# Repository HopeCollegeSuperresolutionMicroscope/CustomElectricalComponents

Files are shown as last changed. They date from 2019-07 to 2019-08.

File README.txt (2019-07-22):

#README

This Directory Serves To Store directions and specifications about electrical components of the microscope setup.

IMPORTANT Point about Schematics and EagleCAD:

	Schematics were created in EagleCAD free version.  These schematics make use of 3rd party libraries provided
        by sites like Element14 and handdrawn library parts based off of datasheets when not found.

	Opening a Schematic In EagleCAD:

		Since the free version of EagleCAD seems to limit all projects to the specific eagle/ folder designated
		 by the program on Install, it is recommended to move the schematic to this directory if intending to do 
		 work on the underlying schematic or pre-Gerber pcb board layout.

		In order to have access to the libraries, from the Eagle Control Panel: 
				Right click Libraries -> Library Manager
				Upper left Tab -> Available
				Browse -> Search for each library in EagleLibraries
				If the library is new it will be added in the Available dialog
				Click on the desired library and click Use button
				You should now see the library in the In Use Tab

Directory Layout:
	|
	|
	| ------- EagleLibraries/
	|		|	:Since Schematics were created in EagleCAD (freeware edition), additional libraries are housed here
	|		|
	|		|
	|		| ------- 3rdParty/ 
	|		|		: Part libraries that were imported from 3rd Party distributors.  See About.txt if wanting to look up revisions.
	|		|
	|		|
	|		| ------- HandCreated/
	|				: Parts that were created from Manufacturer DataSheets by individuals.  
	|				   Add the file name to Confirmed.txt when a pcb footprint has been used and verified.
	|
	|
	| ------- USB_TO_ILDA_Adapter/ 
	|		|	: Electronics for using ILDA device as a laser illumination source
	|		|
	|		|
	|		| ------- (Version) /
	|				|	:See About.txt for Version Different highlights
	|				|
	|				|
	|				| ------- Schematics/
	|				|		: Electrical Connection Schematics
	|				|
	|				|
	|				| ------- Gerber/
	|				|		: Gerber Files for PCBs that have been proven 
	|				|
	|				|
	|				| ------ DataSheets/
	|						: DataSheets Related to important components (ICs at the very least)
	|				
	|
	| ------ USB_TO_RS485_Connection/
	|		|	:Electronic connector and connections for RS-485 Comm with OrientalMotors CRPK
	|		|
	|		|
	|		| ------ Schematics/
	|		|		: Electrical Connections (Since this is a non-standard connection)
	|		|
	|		|
	|		| ------ DataSheets/
	|		|		: DataSheets related to important Components (motor controller and USB adapter)
	|		|
	|		|
	|		| ------ Figures/
	|				: Explanations for adapting the non-standard connection
	|		
	|
	| ------ Power_Supply/
			|	:Electrical connections for using Wall Power to provide stable voltage to OrientalMotors CRPK
			|
			|
			| ------ Schematics/
			|		: Electrical Connections (For pins to terminals etc.)
			|
			|
			| ------ DataSheets/ 
			|		: DataSheets related to important components
			|
			|
			| ------ Figures/
					:Explanation for making connections if there is a difficulty

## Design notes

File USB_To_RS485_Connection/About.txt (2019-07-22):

#About

For the chosen stepper motor from Oriental Motor LLC, a driver is required that must be communicated
with via RS485 protocol.  In order to interface such communication with micro-manager on a PC,
a USB To RS485 adapter must be purchased.

The documentation pertaining to this particular adapter is in regards to the recommended adapter
by Oriental Motor.  Please note, Oriental Motor requires a custom wiring of Ethernet wires into
the adapter.  DO NOT order adapters that are simply listed as USB to RS-485, as Oriental Motor
uses a non-standard wire configuration into their units.  

The appropriate instructions for assembling an RS-485 Adapter with an ethernet cable can be found
in the Schematics Folder.

    Necessary tools: 

		Miniature flat-head screw driver
		Wire Stripper
		Fine Wire Stripper (for stripping the ethernet wires)

See the Documentation and datasheets.

In regards to the driver written for the Autofocus motor at the other end, it must be noted
that the driver IS NOT adapter agnostic.  It makes use of the FTDI USB chip and drivers.  If may
be possible to use another adapter, but one must make certain that it is an FTDI based adapter.

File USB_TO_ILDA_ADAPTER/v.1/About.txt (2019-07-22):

#Version 1
#About.txt

This is the follow-up theoretical designed controller for compliance with the ILDA IO standard.  This
standard requires differential signals at the inputs and it's lack of firm discussion on pin sinking
require a more robust account for potential "operational signal" current draw.

Additionally, DAC power is supplied via wall power with regulators, in order to reduce fluctuations
in voltage that can occur by overloading the load on a set of USB buses for a computer. 

Schematic:

    The schematic is done in theory, but may need revisions upon breadboarding or pcb testing in an 
actual setup.

PCB:

   The PCB has not yet been arranged nor has a breadboard been proven yet.  A finalized Gerber file
should be introduced after a successful iteration and testing.

Software

    C++ code was written as a .dll on Micro-manager for the alpha version explicitly. The Version 1
attempts to implement the same USB bridge triggers so that there is no need to change the .dll for
the sake of changing hardware.

Further expansions to the other optional ILDA pins may be achieved in a future iteration with adjustments 
to the .dll.

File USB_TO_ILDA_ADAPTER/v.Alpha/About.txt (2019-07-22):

#Version Alpha
#About.txt

The first prototype that was used to maintain a stable control over the PRO-1600RGB laser from 
Laserworld.  This prototype is what was used to do primary testing and proof of this system as
integrated into uManager microscopy setup software.  It, however, implements an erroneous reading
of the ILDA standard and as such is not guaranteed to work with all ILDA IO pins.

As such, this alpha version stands as proof of control of the PRO-1600RGB and may be tested against 
other ILDA laser boxes if so desired to ensure performance. 

Schematic:

    The schematic makes use of a Deprected switch (see schematic itself for details).  This switch
will become a production chokepoint.  Efforts to formalize and proof v1.0 move toward this.

PCB:

   The alpha prototype exists in a breadboarded state in the setup this lab tested against.  As such,
there are no Gerber files at this moment.  It is seen as a better use of time to work on proving
the v1.0 PCB instead.  The following version however will require a reworking of uManager Device 
Library code to accomodate an increase in IO if that is desired.

Software

    C++ code was written as a .dll on Micro-manager for the alpha version explicitly.  In order to 
test the setup this lab used.

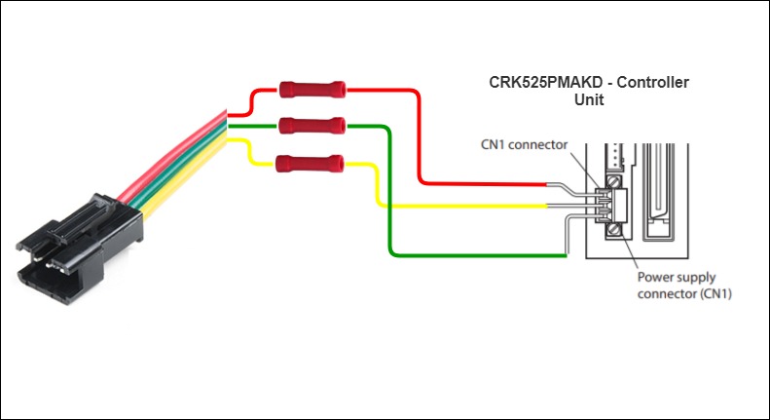
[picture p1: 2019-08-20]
Autofocus_Motor_Power_Supply/Schematics/PowerSupplyCableConnection.jpg

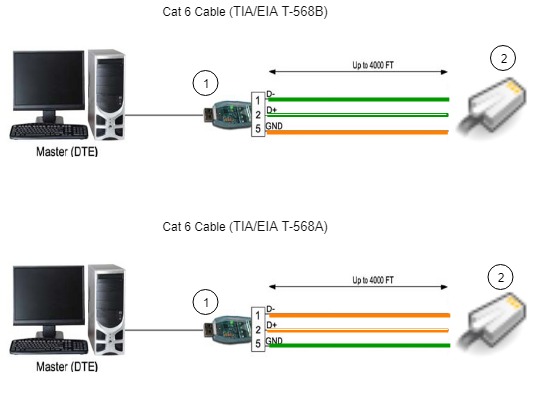
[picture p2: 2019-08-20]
Autofocus_Motor_Power_Supply/Schematics/ConnectingServoToComputer.jpg

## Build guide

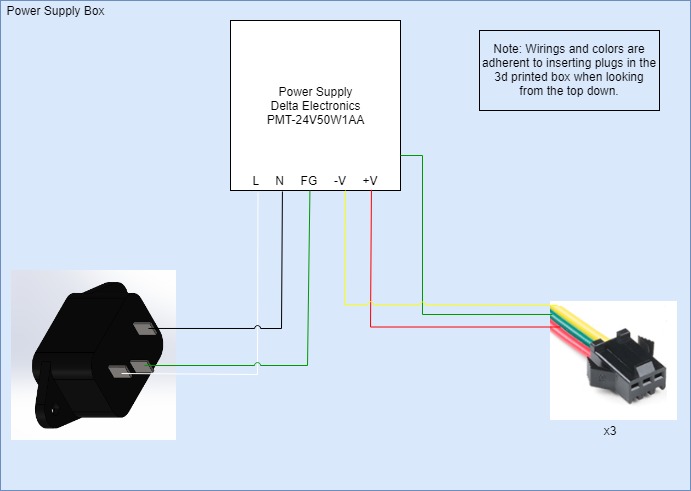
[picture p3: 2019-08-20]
Autofocus_Motor_Power_Supply/Schematics/PowerSupplyInternalWiring.jpg

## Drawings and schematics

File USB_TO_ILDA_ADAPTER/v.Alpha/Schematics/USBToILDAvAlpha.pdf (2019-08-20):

# GND ⁺⁵V

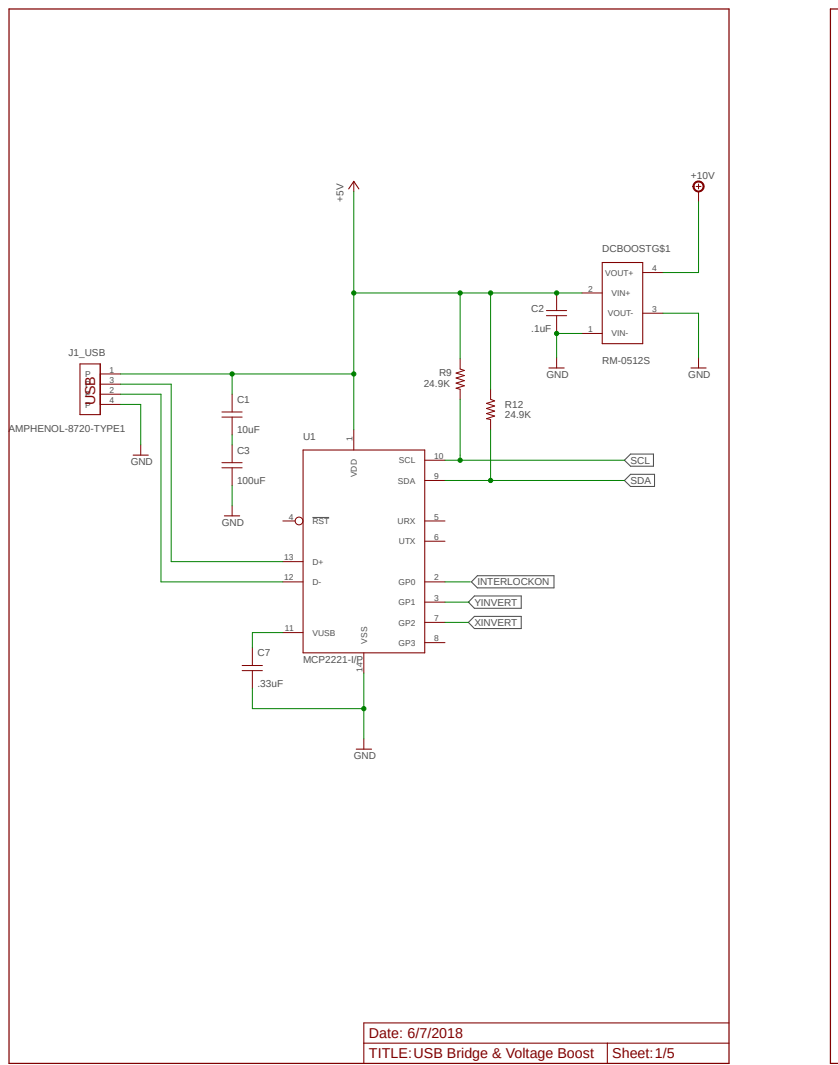
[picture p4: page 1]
MCP2221-I/P; AMPHENOL-8720-TYPE1; GND; VDD; J1_USB; DCBOOSTG$1 VIN- 1; VIN+ 2; VOUT-; 3 VOUT+; SCL; YINVERT; XINVERT; INTERLOCKON; SDA; USB Bridge & Voltage Boost; 1/5 USB; Date:; TITLE:; Sheet:

1 VSS 14 D+ 13 D- 12 SCL 10 SDA 9 URX 5 UTX 6 GP0 2 GP1 3 GP2 7 GP3 8 RST 4 VUSB 11

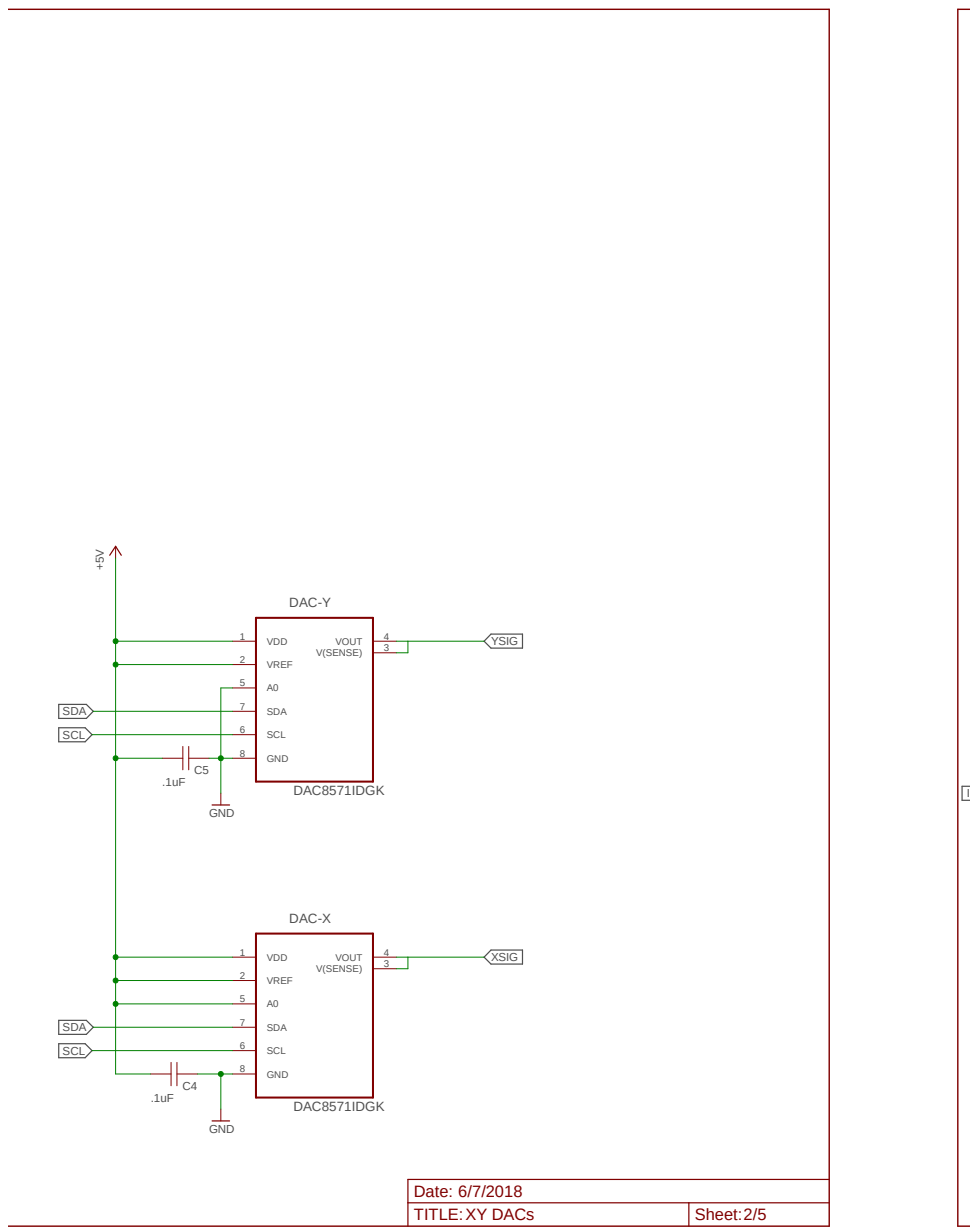
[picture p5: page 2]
DAC8571IDGK; GND; GND ⁺⁵V; VDD 1; VREF 2; SDA 7; SCL 6; GND 8; VOUT; 4 V(SENSE); 3 DAC-Y; 3 DAC-X; YSIG; XSIG; SCL; INTERLOCKON; SDA; XY DACs

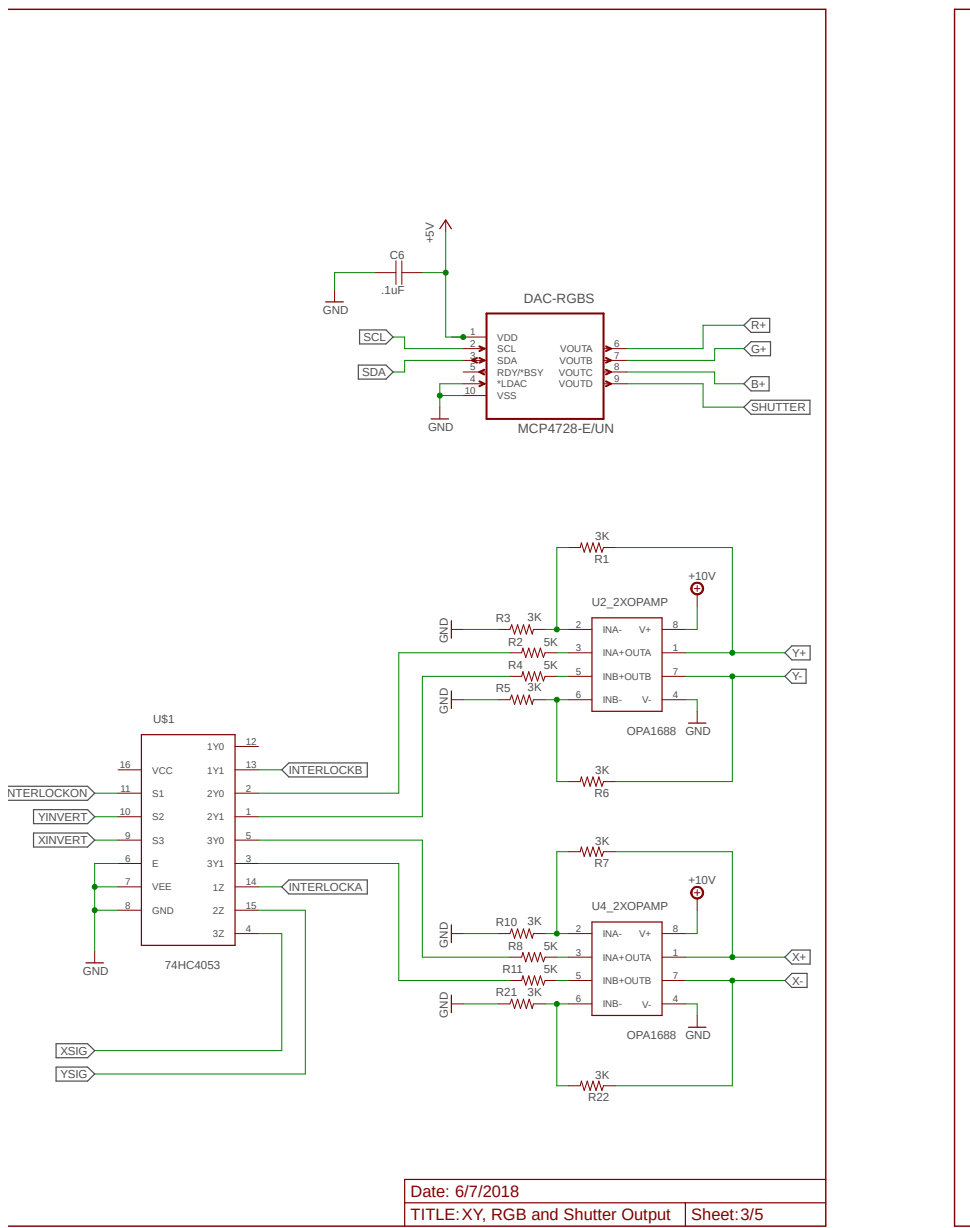
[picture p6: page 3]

GND GND

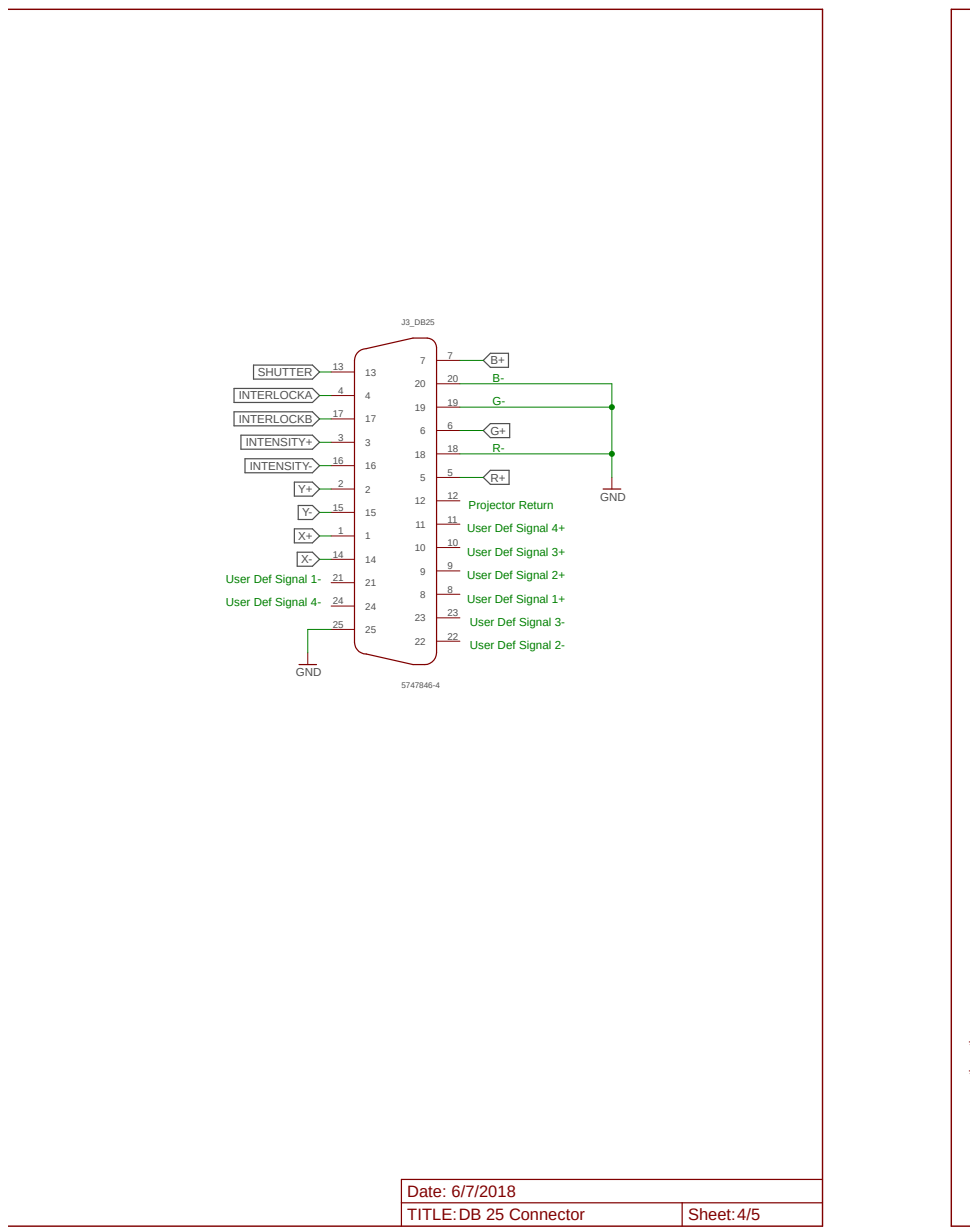
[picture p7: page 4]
5747846-4 GND; GND; SHUTTER; INTENSITY+; INTENSITY-; INTERLOCKB; INTERLOCKA; DB 25 Connector; User Def Signal 3+; User Def Signal 4+; Projector Return

User Def Signal 2+
User Def Signal 1+
User Def Signal 3-
User Def Signal 2-

User Def Signal 1-
User Def Signal 4-

* List is non-exhaustive and seeks to use proven ICs from the Alpha version
** See ILDA standards to confirm. These are the most glaring issues.

## RGB & Shutter Voltage

5/5

# Alpha Version Notes:

# Setup is proven against PRO-1600RGB from Laserworld, but DOES NOT adhere

to ILDA specifcation.

# Changes Needed For ILDA Conformance**

# +/- Signals need to be differential not ground referenced

# Separate Power supply to account for lax current spec (USB cannot meet the maximum circumstance)

# Improvements From Alpha:*

# ILDA Standard Conformance

# 74HC4503 is deprecated and must be replaced

# PCB must be finalized and tested for conformance (Alpha was in a breadboard)

# Move to External Power and regulation (USB fluctuates due to loads)

## * List is non-exhaustive and seeks to use proven ICs from the Alpha version

** See ILDA standards to confirm. These are the most glaring issues.
Other non-important conformance may be additional IO connections on the DB-25 Connector, etc.

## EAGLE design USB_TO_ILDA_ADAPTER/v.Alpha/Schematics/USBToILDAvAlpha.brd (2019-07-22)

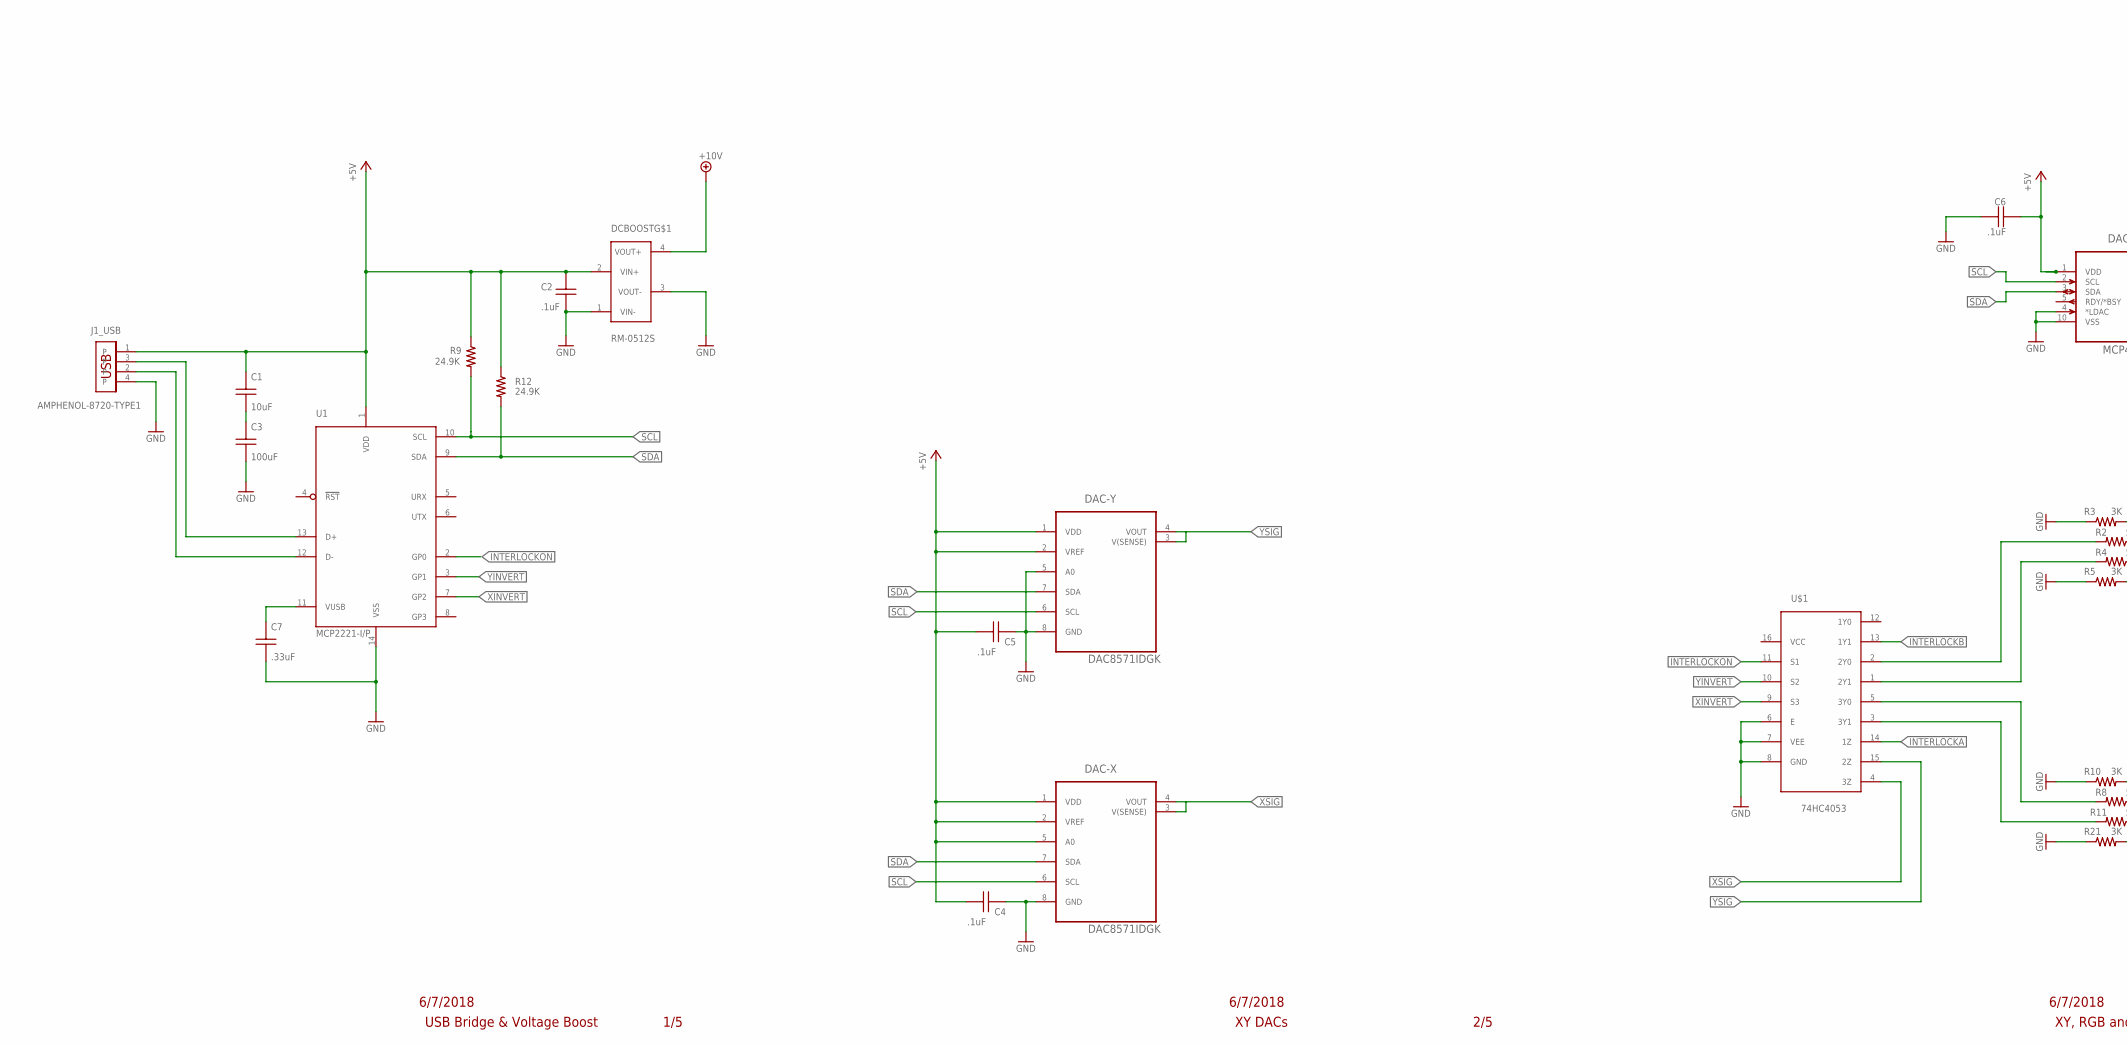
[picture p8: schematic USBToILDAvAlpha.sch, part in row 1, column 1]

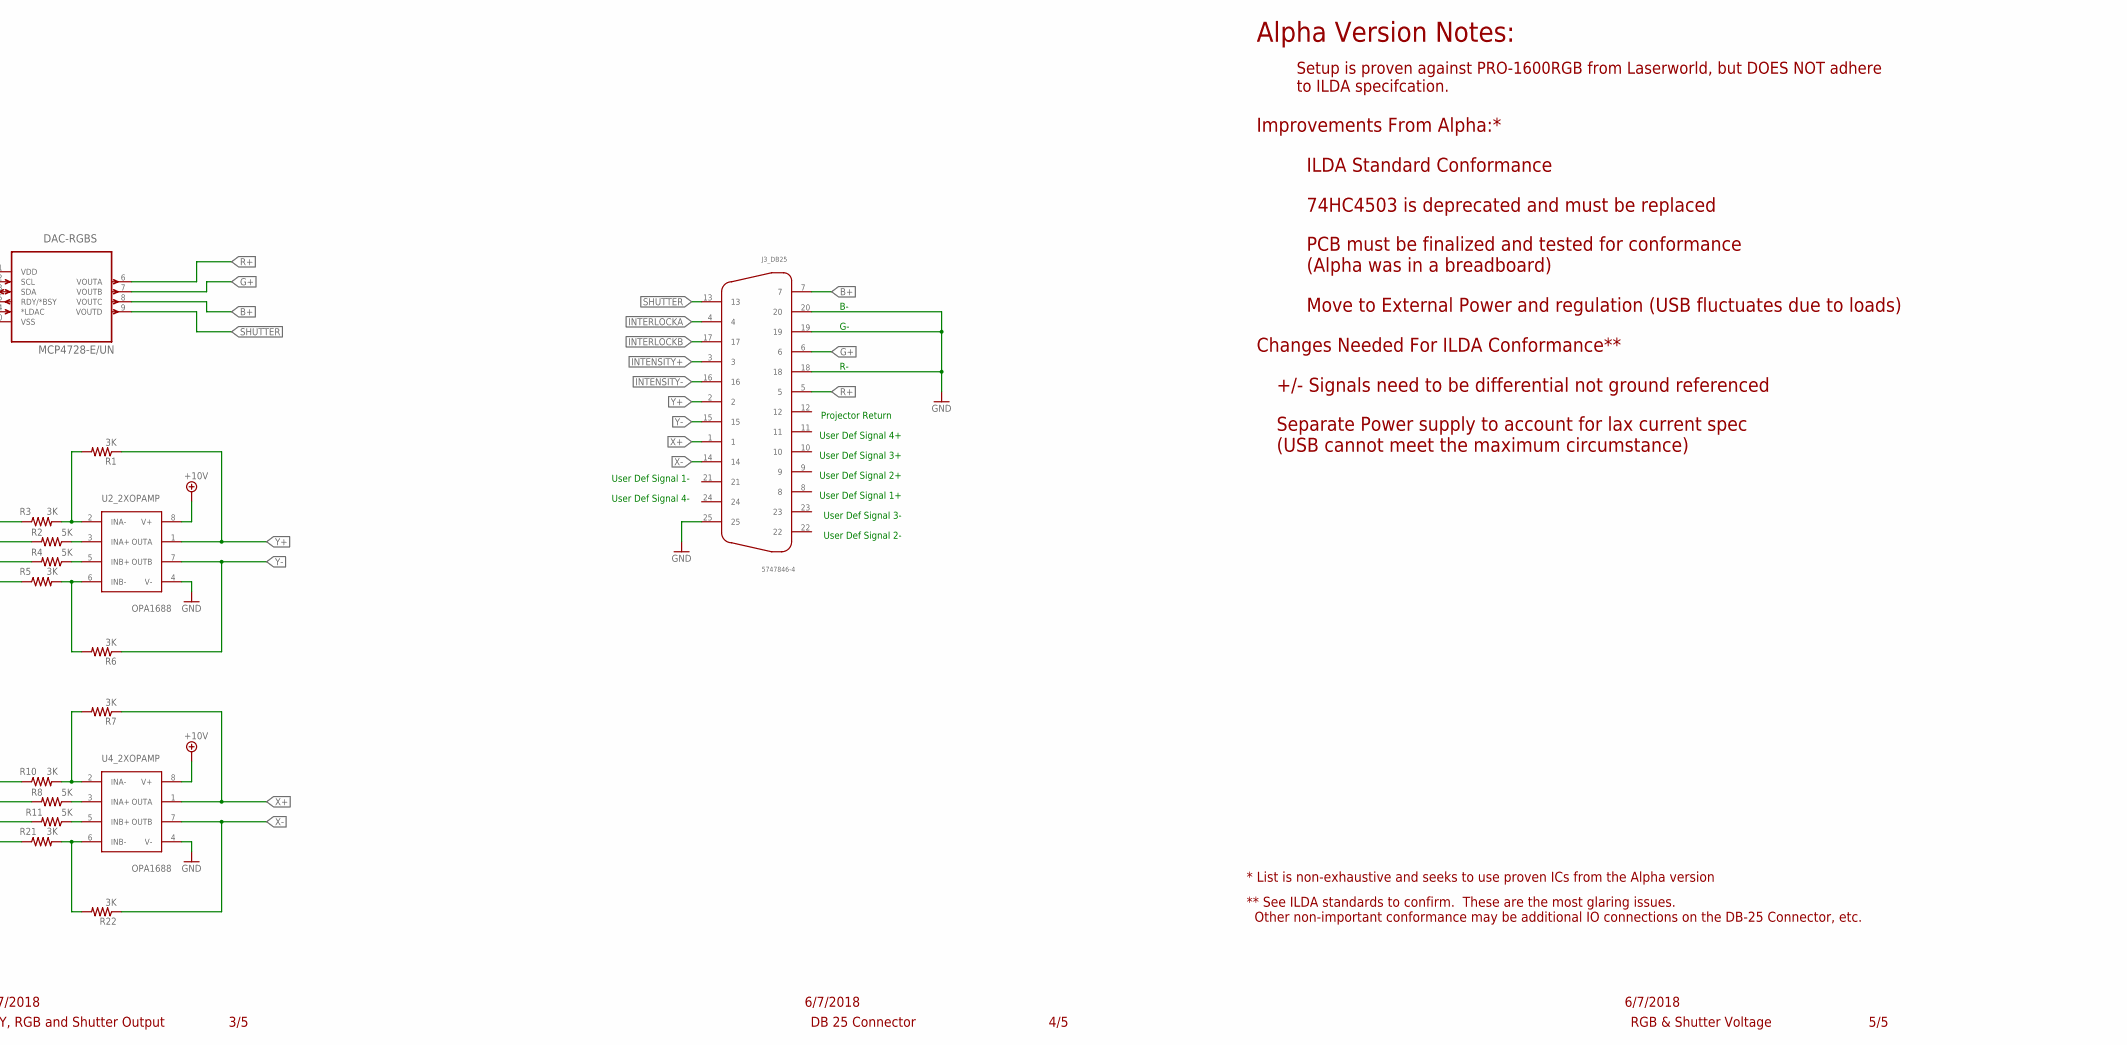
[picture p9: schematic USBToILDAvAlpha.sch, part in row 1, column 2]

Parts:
C1: 10uF; WM1
C2, C4, C5, C6: .1uF; WM1
C3: 100uF; WM1
C7: .33uF; WM1
DAC-RGBS: MCP4728-E/UN; SOP50P490X110-10N
DAC-X: DAC8571IDGK; SOP65P490X110-8N
DAC-Y: DAC8571IDGK; SOP65P490X110-8N
DCBOOST: RM-0512S; SIP-4
J1_: AMPHENOL-8720-TYPE1; 87520
J3_: 5747846-4
R1, R3, R5, R6, R7, R10, R21, R22: 3K; R01005
R2, R4, R8, R11: 5K; R01005
R9, R12: 24.9K; R01005
U1: MCP2221-I/P; DIL14
U2, U4: OPA1688; SOIC-8
U$1: 74HC4053; SO16

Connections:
+5V: C1.P$1 (A), C2.P$1 (A), C4.P$1 (A), C5.P$1 (A), C6.P$2 (B), DAC-RGBS.1 (VDD), DAC-X.1 (VDD), DAC-X.2 (VREF), DAC-X.5 (A0), DAC-Y.1 (VDD), DAC-Y.2 (VREF), DCBOOST.2 (VIN+), J1_.1, R9.1, R12.1, U1.1 (VDD)
+9V: DCBOOST.4 (VOUT+)
+10V: U2.8 (V+), U4.8 (V+)
B+: DAC-RGBS.8 (VOUTC), J3_.7
G+: DAC-RGBS.7 (VOUTB), J3_.6
GND: C2.P$2 (B), C3.P$2 (B), C4.P$2 (B), C5.P$2 (B), C6.P$1 (A), C7.P$2 (B), DAC-RGBS.4 (*LDAC), DAC-RGBS.10 (VSS), DAC-X.8 (GND), DAC-Y.5 (A0), DAC-Y.8 (GND), DCBOOST.1 (VIN-), DCBOOST.3 (VOUT-), J1_.4, J3_.18, J3_.19, J3_.20, J3_.25, R3.1, R5.1, R10.1, R21.1, U1.14 (VSS), U2.4 (V-), U4.4 (V-), U$1.6 (E), U$1.7 (VEE), U$1.8 (GND)
INTENSITY+: J3_.3
INTENSITY-: J3_.16
INTERLOCKA: J3_.4, U$1.14 (1Z)
INTERLOCKB: J3_.17, U$1.13 (1Y1)
INTERLOCKON: U1.2 (GP0), U$1.11 (S1)
unnamed: C1.P$2 (B), C3.P$1 (A)
unnamed: J1_.2, U1.12 (D-)
unnamed: J1_.3, U1.13 (D+)
unnamed: R1.2, R3.2, U2.2 (INA-)
unnamed: R2.1, U2.3 (INA+)
unnamed: R2.2, U$1.2 (2Y0)
unnamed: R7.2, R10.2, U4.2 (INA-)
unnamed: R8.1, U4.3 (INA+)
unnamed: R8.2, U$1.5 (3Y0)
unnamed: R4.2, U$1.1 (2Y1)
unnamed: R4.1, U2.5 (INB+)
unnamed: R11.2, U$1.3 (3Y1)
unnamed: R5.2, R6.2, U2.6 (INB-)
unnamed: C7.P$1 (A), U1.11 (VUSB)
unnamed: R11.1, U4.5 (INB+)
unnamed: R21.2, R22.2, U4.6 (INB-)
R+: DAC-RGBS.6 (VOUTA), J3_.5
SCL: DAC-RGBS.2 (SCL), DAC-X.6 (SCL), DAC-Y.6 (SCL), R9.2, U1.10 (SCL)
SDA: DAC-RGBS.3 (SDA), DAC-X.7 (SDA), DAC-Y.7 (SDA), R12.2, U1.9 (SDA)
SHUTTER: J3_.13
X+: J3_.1, R7.1, U4.1 (OUTA)
X-: J3_.14, R22.1, U4.7 (OUTB)
XINVERT: U1.7 (GP2), U$1.9 (S3)
XSIG: DAC-X.3 (V(SENSE)), DAC-X.4 (VOUT), U$1.4 (3Z)
Y+: J3_.2, R1.1, U2.1 (OUTA)
Y-: J3_.15, R6.1, U2.7 (OUTB)
YINVERT: U1.3 (GP1), U$1.10 (S2)
YSIG: DAC-Y.3 (V(SENSE)), DAC-Y.4 (VOUT), U$1.15 (2Z)

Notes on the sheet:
User Def Signal 1+
User Def Signal 2+
User Def Signal 3+
User Def Signal 4+
Projector Return
User Def Signal 1-
User Def Signal 2-
User Def Signal 3-
User Def Signal 4-
6/7/2018
RGB & Shutter Voltage
4/5
DB 25 Connector
5/5
USB Bridge & Voltage Boost
1/5
XY, RGB and Shutter Output
3/5
XY DACs
2/5
Alpha Version Notes:
Setup is proven against PRO-1600RGB from Laserworld, but DOES NOT adhere to ILDA specifcation.
Changes Needed For ILDA Conformance**
+/- Signals need to be differential not ground referenced
Separate Power supply to account for lax current spec (USB cannot meet the maximum circumstance)
Improvements From Alpha:*
ILDA Standard Conformance
74HC4503 is deprecated and must be replaced
PCB must be finalized and tested for conformance (Alpha was in a breadboard)
Move to External Power and regulation (USB fluctuates due to loads)
* List is non-exhaustive and seeks to use proven ICs from the Alpha version
** See ILDA standards to confirm. These are the most glaring issues. Other non-important conformance may be additional IO connections on the DB-25 Connector, etc.

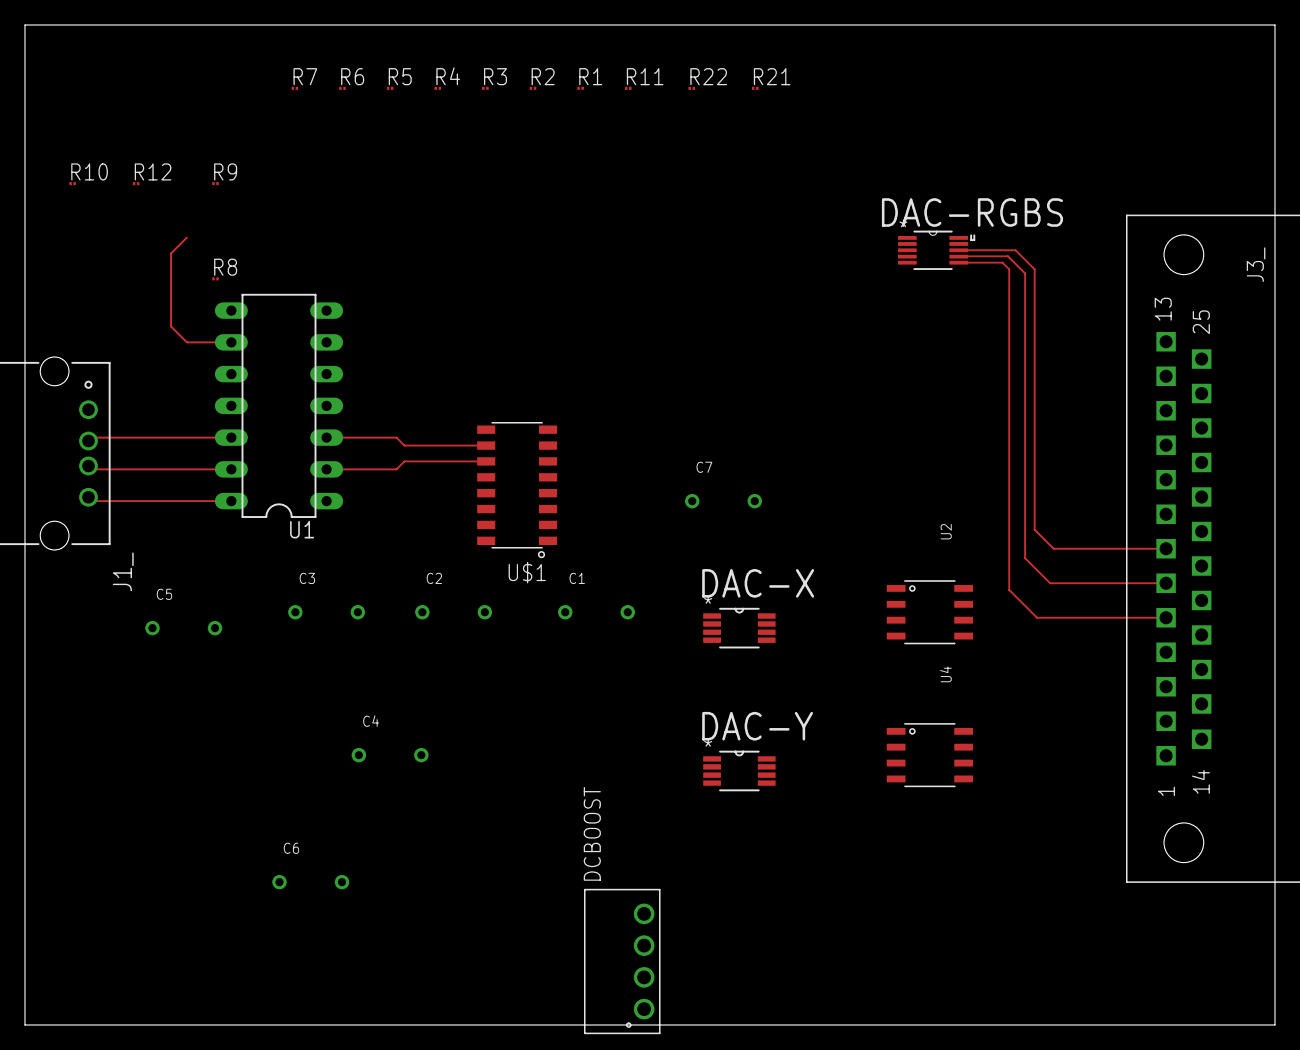
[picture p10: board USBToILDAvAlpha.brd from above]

Board: 2 copper layers, 100.0 x 80.0 mm, 31 parts (0 on the bottom side), 35 nets.

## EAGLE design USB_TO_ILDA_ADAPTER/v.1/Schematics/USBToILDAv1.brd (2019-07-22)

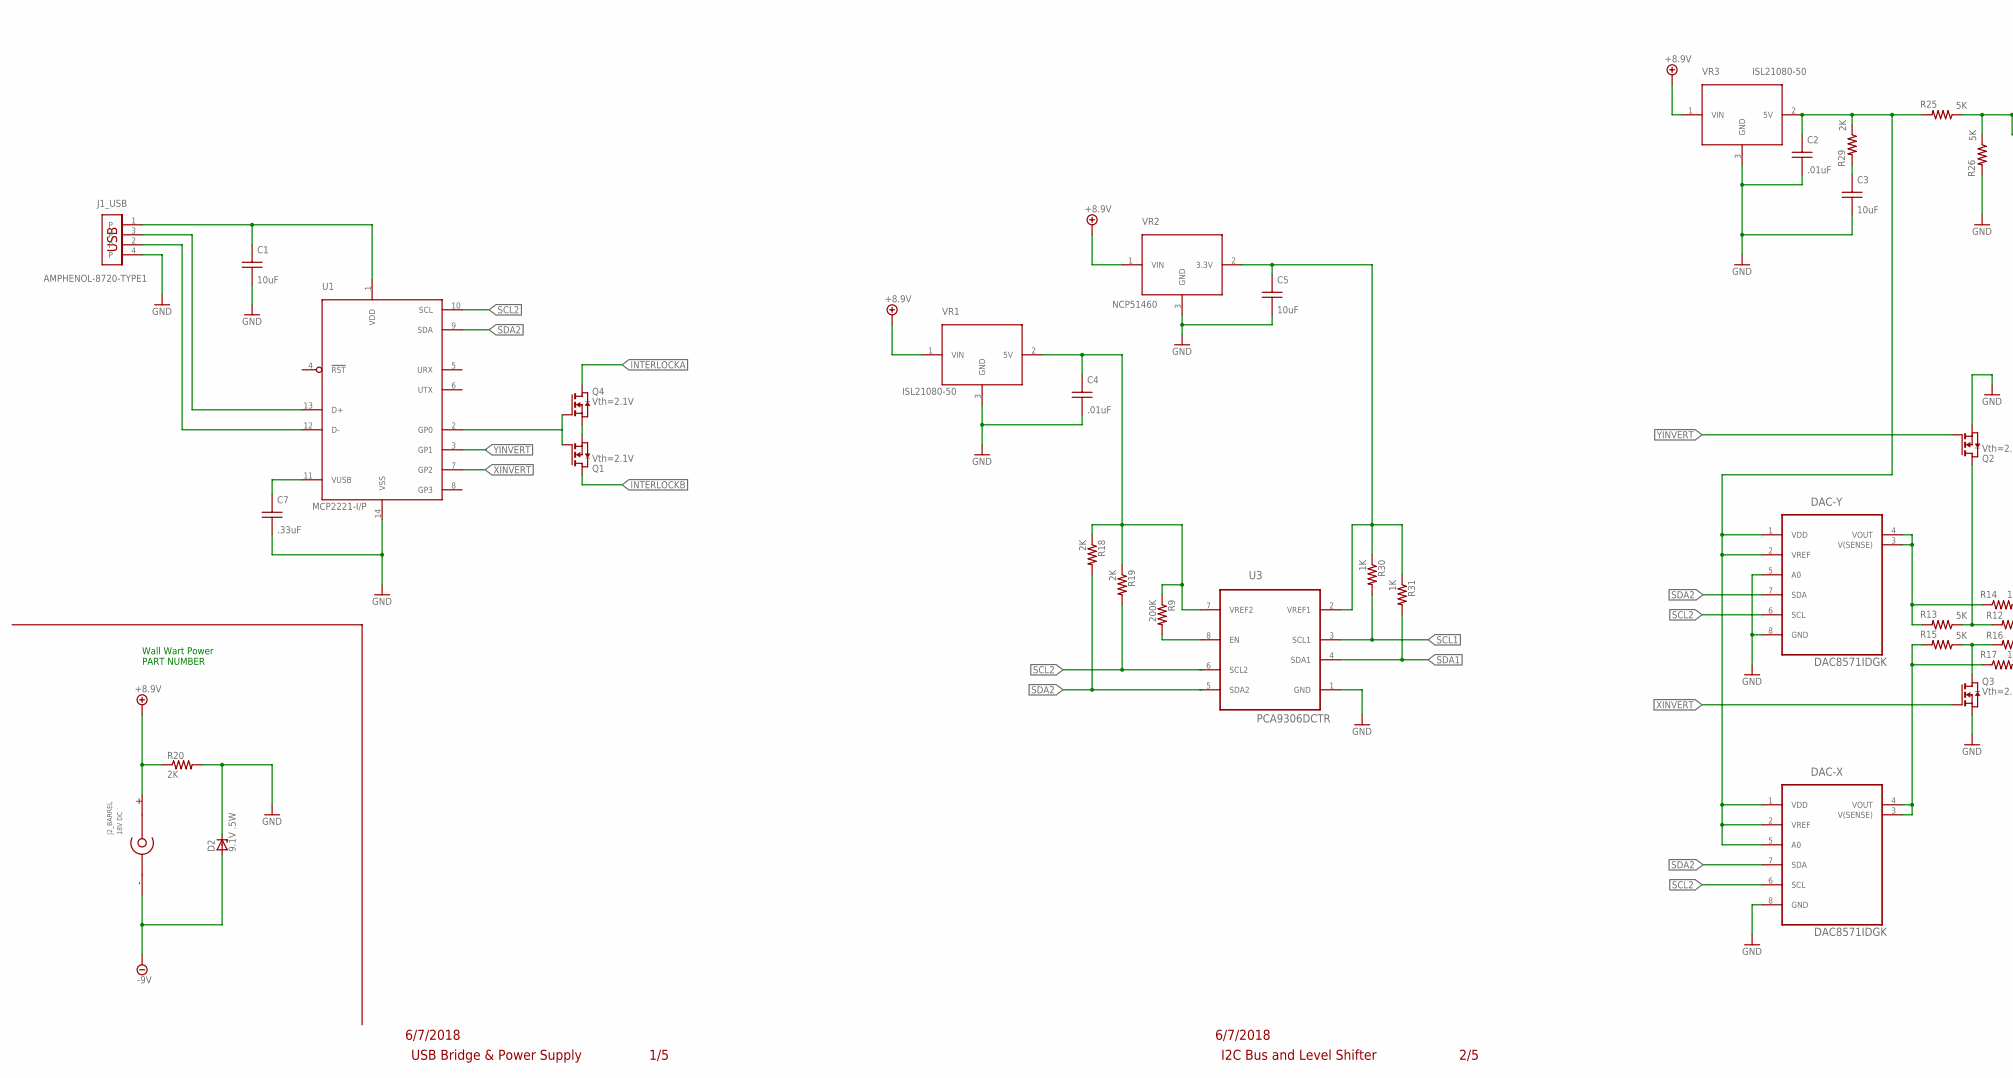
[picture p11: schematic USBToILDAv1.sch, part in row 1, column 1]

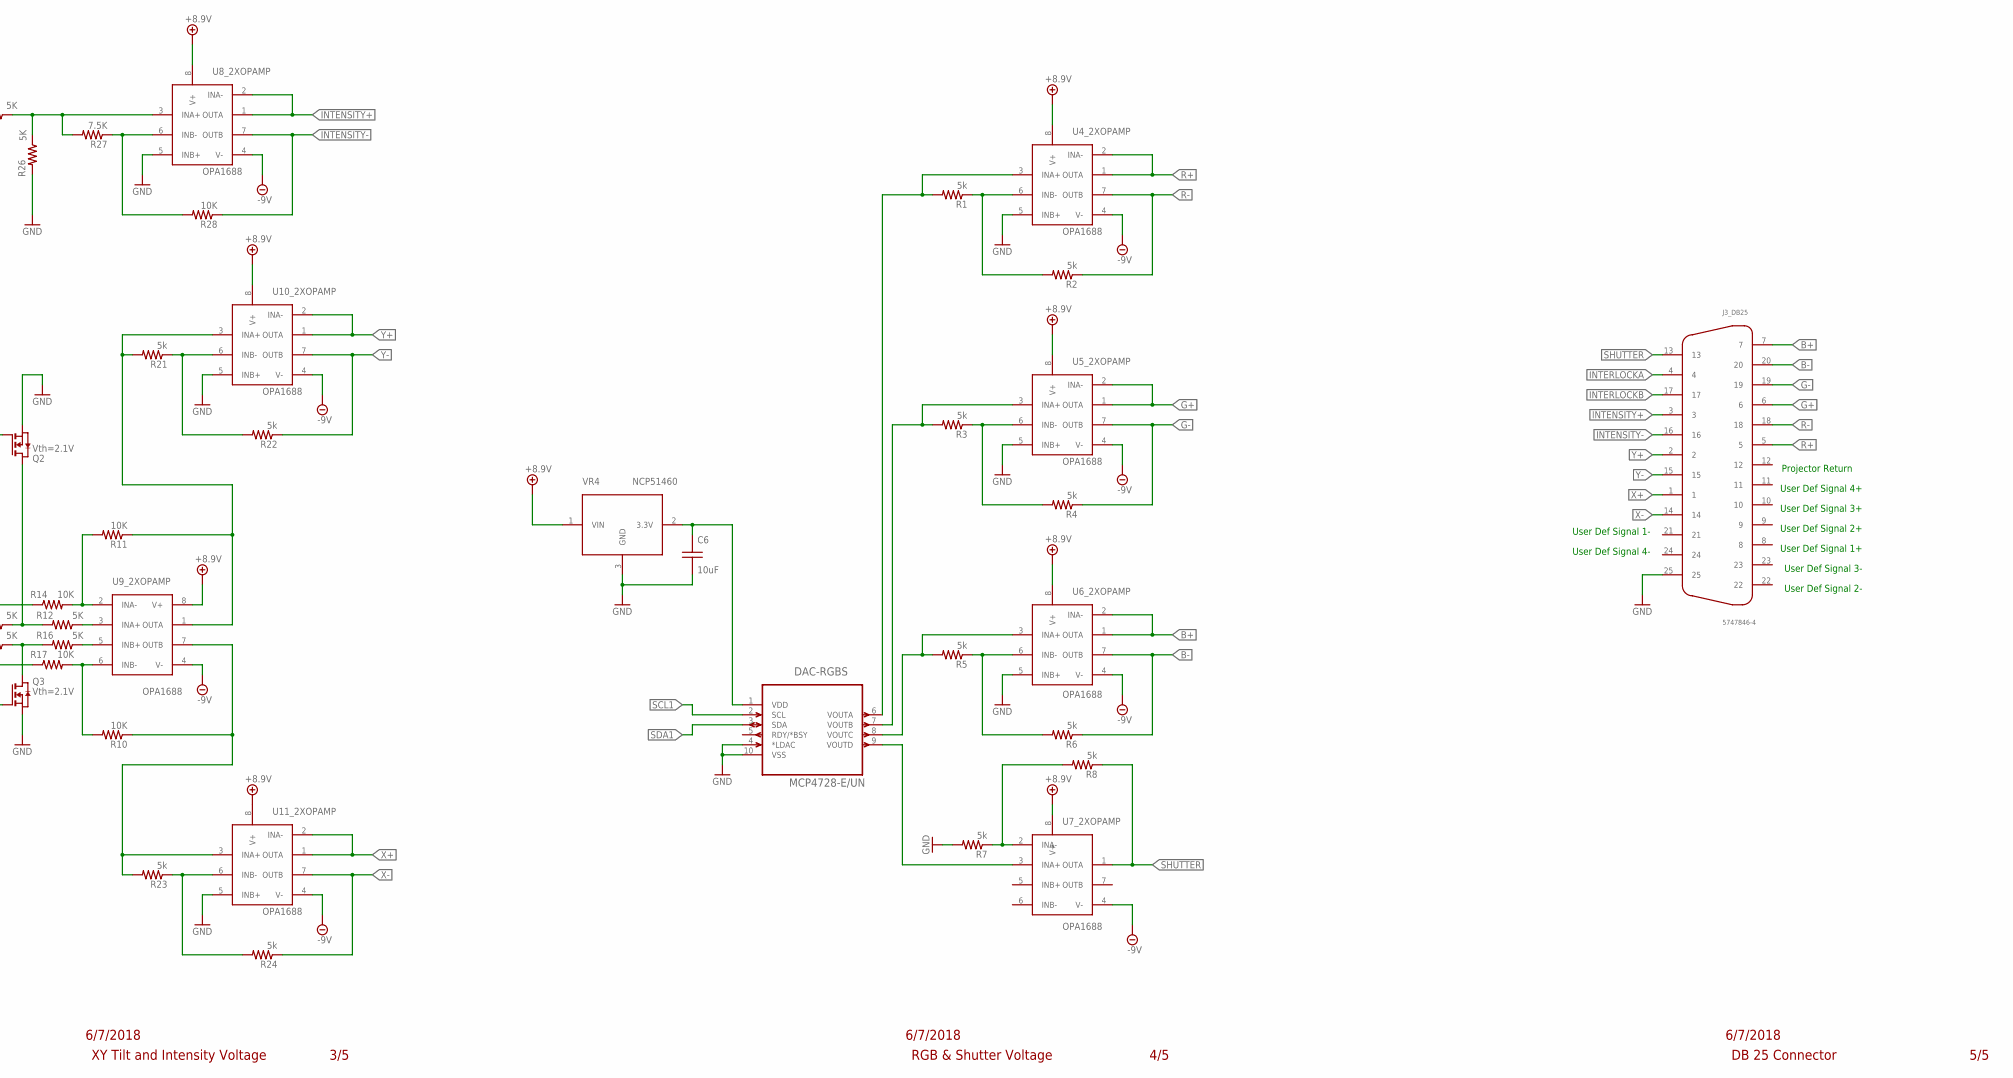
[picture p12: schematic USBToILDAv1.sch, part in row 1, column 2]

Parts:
C1, C3, C5, C6: 10uF; WM1
C2, C4: .01uF; WM1
C7: .33uF; WM1
D2: 9.1V .5W; DO35Z10
DAC-RGBS: MCP4728-E/UN; SOP50P490X110-10N
DAC-X: DAC8571IDGK; SOP65P490X110-8N
DAC-Y: DAC8571IDGK; SOP65P490X110-8N
J1_: AMPHENOL-8720-TYPE1; 87520
J2_BARREL: 18V DC; PJ-036AH-SMT-TR
J3_: 5747846-4
Q1, Q2, Q3, Q4: Vth=2.1V; SOT-26
R1, R2, R3, R4, R5, R6, R7, R8, R21, R22, R23, R24: 5k; R01005
R9: 200K; R01005
R10, R11, R14, R17, R28: 10K; R01005
R12, R13, R15, R16, R25, R26: 5K; R01005
R18, R19, R20, R29: 2K; R01005
R27: 7.5K; R01005
R30, R31: 1K; R01005
U1: MCP2221-I/P; DIL14
U3: PCA9306DCTR; SOP65P400X130-8N
U4, U5, U6, U7, U8, U9, U10, U11: OPA1688; SOIC-8
VR1, VR3: ISL21080-50; SOT23-CASE308
VR2, VR4: NCP51460; SOT-23-CASE318

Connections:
+8.9V: J2_BARREL.1 (+), R20.1, U4.8 (V+), U5.8 (V+), U6.8 (V+), U7.8 (V+), U8.8 (V+), U9.8 (V+), U10.8 (V+), U11.8 (V+), VR1.1 (VIN), VR2.1 (VIN), VR3.1 (VIN), VR4.1 (VIN)
-9V: D2.A, J2_BARREL.2 (-), J2_BARREL.3 (-), U4.4 (V-), U5.4 (V-), U6.4 (V-), U7.4 (V-), U8.4 (V-), U9.4 (V-), U10.4 (V-), U11.4 (V-)
B+: J3_.7, U6.1 (OUTA), U6.2 (INA-)
B-: J3_.20, R6.1, U6.7 (OUTB)
G+: J3_.6, U5.1 (OUTA), U5.2 (INA-)
G-: J3_.19, R4.1, U5.7 (OUTB)
GND: C2.P$2 (B), C3.P$2 (B), C4.P$2 (B), C5.P$2 (B), C6.P$2 (B), C7.P$2 (B), D2.C, DAC-RGBS.4 (*LDAC), DAC-RGBS.10 (VSS), DAC-X.8 (GND), DAC-Y.5 (A0), DAC-Y.8 (GND), J1_.4, J3_.25, Q2.S, Q3.S, R7.2, R20.2, R26.2, U1.14 (VSS), U3.1 (GND), U4.5 (INB+), U5.5 (INB+), U6.5 (INB+), U8.5 (INB+), U10.5 (INB+), U11.5 (INB+), VR1.3 (GND), VR2.3 (GND), VR3.3 (GND), VR4.3 (GND)
INTENSITY+: J3_.3, U8.1 (OUTA), U8.2 (INA-)
INTENSITY-: J3_.16, R28.1, U8.7 (OUTB)
INTERLOCK-I/O: Q1.G, Q4.G, U1.2 (GP0)
INTERLOCKA: J3_.4, Q4.D1 (D), Q4.D2 (D), Q4.D3 (D), Q4.D4 (D)
INTERLOCKB: J3_.17, Q1.D1 (D), Q1.D2 (D), Q1.D3 (D), Q1.D4 (D)
unnamed: J1_.2, U1.12 (D-)
unnamed: J1_.3, U1.13 (D+)
unnamed: C1.P$1 (A), J1_.1, U1.1 (VDD)
unnamed: R9.2, U3.8 (EN)
unnamed: DAC-RGBS.6 (VOUTA), R1.2, U4.3 (INA+)
unnamed: R7.1, R8.2, U7.2 (INA-)
unnamed: R1.1, R2.2, U4.6 (INB-)
unnamed: C6.P$1 (A), DAC-RGBS.1 (VDD), VR4.2 (3.3V)
unnamed: DAC-RGBS.7 (VOUTB), R3.2, U5.3 (INA+)
unnamed: R25.1, R26.1, R27.2, U8.3 (INA+)
unnamed: R3.1, R4.2, U5.6 (INB-)
unnamed: C2.P$1 (A), DAC-X.1 (VDD), DAC-X.2 (VREF), DAC-X.5 (A0), DAC-Y.1 (VDD), DAC-Y.2 (VREF), R25.2, R29.1, VR3.2 (5V)
unnamed: DAC-RGBS.8 (VOUTC), R5.2, U6.3 (INA+)
unnamed: R11.1, R21.2, U9.1 (OUTA), U10.3 (INA+)
unnamed: R5.1, R6.2, U6.6 (INB-)
unnamed: C7.P$1 (A), U1.11 (VUSB)
unnamed: DAC-RGBS.9 (VOUTD), U7.3 (INA+)
unnamed: C4.P$1 (A), R9.1, R18.1, R19.1, U3.7 (VREF2), VR1.2 (5V)
unnamed: Q1.S, Q4.S
unnamed: R11.2, R14.2, U9.2 (INA-)
unnamed: R12.1, U9.3 (INA+)
unnamed: Q2.D1 (D), Q2.D2 (D), Q2.D3 (D), Q2.D4 (D), R12.2, R13.1
unnamed: DAC-Y.3 (V(SENSE)), DAC-Y.4 (VOUT), R13.2, R14.1
unnamed: DAC-X.3 (V(SENSE)), DAC-X.4 (VOUT), R15.2, R17.1
unnamed: Q3.D1 (D), Q3.D2 (D), Q3.D3 (D), Q3.D4 (D), R15.1, R16.2
unnamed: R16.1, U9.5 (INB+)
unnamed: R10.2, R17.2, U9.6 (INB-)
unnamed: R10.1, R23.2, U9.7 (OUTB), U11.3 (INA+)
unnamed: C3.P$1 (A), R29.2
unnamed: R21.1, R22.2, U10.6 (INB-)
unnamed: R23.1, R24.2, U11.6 (INB-)
unnamed: R27.1, R28.2, U8.6 (INB-)
unnamed: C5.P$1 (A), R30.1, R31.1, U3.2 (VREF1), VR2.2 (3.3V)
R+: J3_.5, U4.1 (OUTA), U4.2 (INA-)
R-: J3_.18, R2.1, U4.7 (OUTB)
SCL1: DAC-RGBS.2 (SCL), R30.2, U3.3 (SCL1)
SCL2: DAC-X.6 (SCL), DAC-Y.6 (SCL), R19.2, U1.10 (SCL), U3.6 (SCL2)
SDA1: DAC-RGBS.3 (SDA), R31.2, U3.4 (SDA1)
SDA2: DAC-X.7 (SDA), DAC-Y.7 (SDA), R18.2, U1.9 (SDA), U3.5 (SDA2)
SHUTTER: J3_.13, R8.1, U7.1 (OUTA)
X+: J3_.1, U11.1 (OUTA), U11.2 (INA-)
X-: J3_.14, R24.1, U11.7 (OUTB)
XINVERT: Q3.G, U1.7 (GP2)
Y+: J3_.2, U10.1 (OUTA), U10.2 (INA-)
Y-: J3_.15, R22.1, U10.7 (OUTB)
YINVERT: Q2.G, U1.3 (GP1)

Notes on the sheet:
User Def Signal 1+
User Def Signal 2+
User Def Signal 3+
User Def Signal 4+
Projector Return
User Def Signal 1-
User Def Signal 2-
User Def Signal 3-
User Def Signal 4-
Wall Wart Power PART NUMBER
6/7/2018
RGB & Shutter Voltage
4/5
DB 25 Connector
5/5
USB Bridge & Power Supply
1/5
XY Tilt and Intensity Voltage
3/5
I2C Bus and Level Shifter
2/5

Board: 2 copper layers, 63 parts (0 on the bottom side), 58 nets, no tracks yet.

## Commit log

2019-07-22 Initial Commit of bread-boarded alpha, and to be tested v1
    [USBToILDAv1.brd, USBToILDAv1.sch, USBToILDAvAlpha.brd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]
2019-08-20 Added instructions for creating an insulated and accessible power supply box
2019-08-20 Pdf of schematic for accessibility
